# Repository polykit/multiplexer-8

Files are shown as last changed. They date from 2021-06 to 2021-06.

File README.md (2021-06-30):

# Polykit Multiplexer 16:8

This repository contains schematics and PCB layout of a 2x8 to 8 channel multiplexer. It can be used to switch between different waveforms of a polyphonic oscillator. It is based on four 4066 bilateral switches and can handle a 10Vpp signal. It is powered by +-12V Eurorack style power supply.

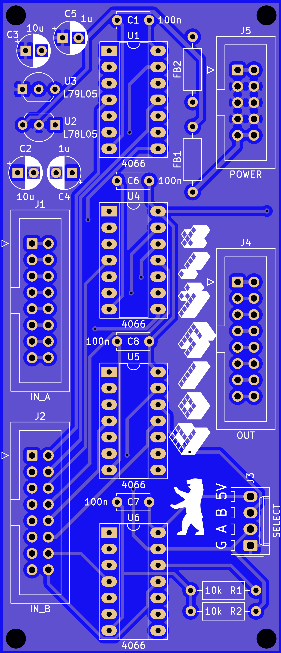
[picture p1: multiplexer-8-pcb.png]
Polykit Multiplexer 8 PCB


## References

https://www.ti.com/lit/ds/symlink/cd4066b.pdf

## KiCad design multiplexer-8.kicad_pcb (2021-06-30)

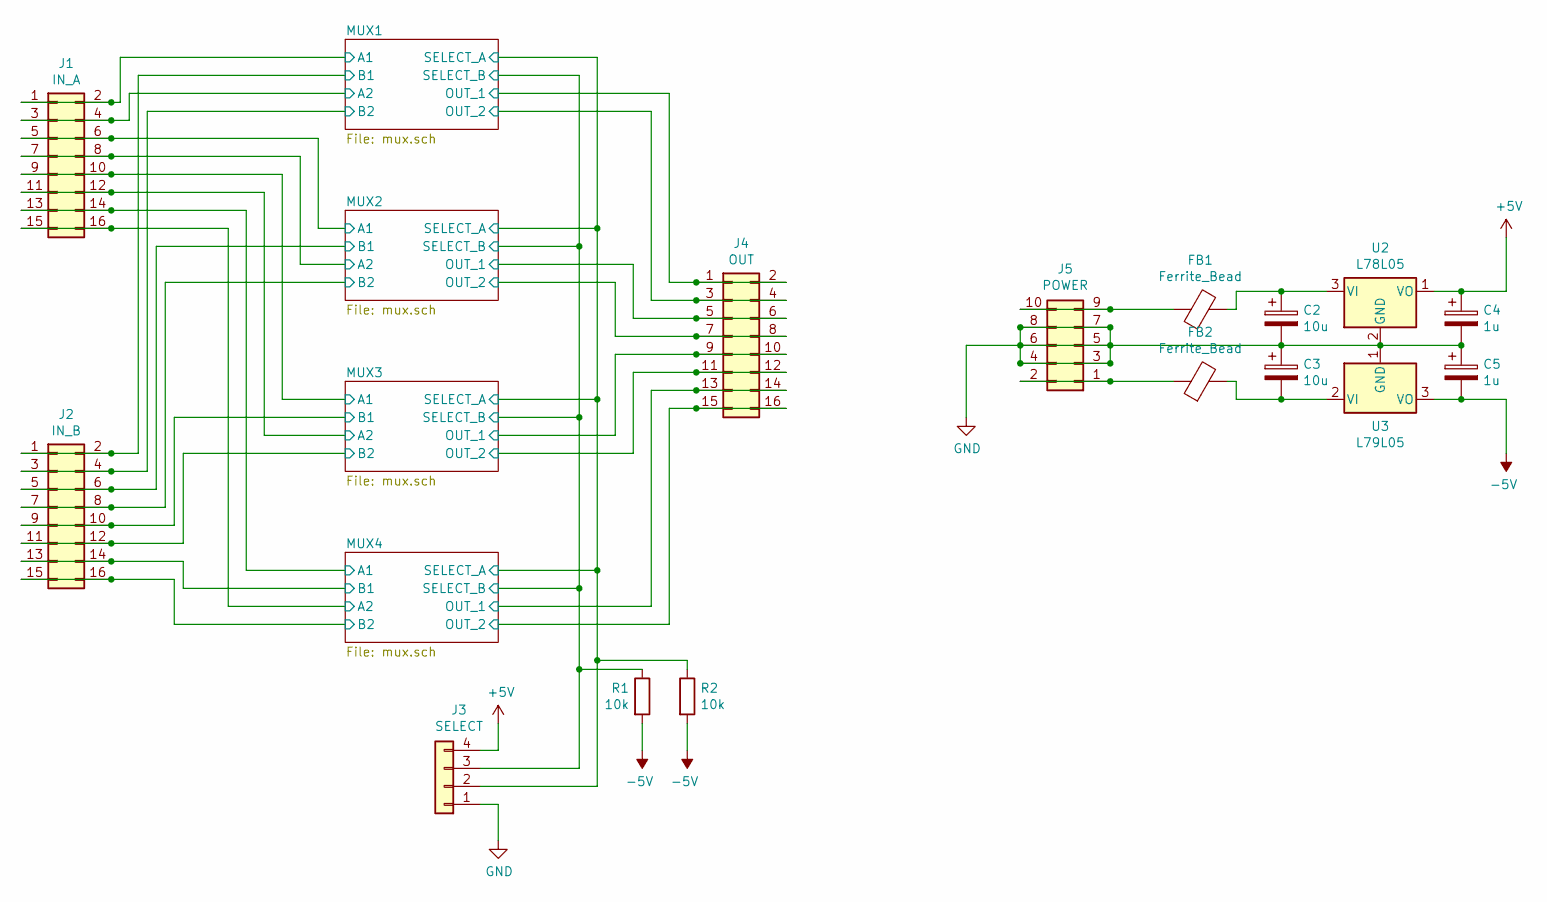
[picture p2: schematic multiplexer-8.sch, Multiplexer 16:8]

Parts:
C2, C3: 10u; CP_Radial_D5.0mm_P2.50mm
C4, C5: 1u; CP_Radial_D5.0mm_P2.50mm
FB1, FB2: Ferrite_Bead; R_Axial_DIN0207_L6.3mm_D2.5mm_P10.16mm_Horizontal
J1: IN_A; IDC-Header_2x08_P2.54mm_Vertical
J2: IN_B; IDC-Header_2x08_P2.54mm_Vertical
J3: SELECT; Molex_KK-254_AE-6410-04A_1x04_P2.54mm_Vertical
J4: OUT; IDC-Header_2x08_P2.54mm_Vertical
J5: POWER; IDC-Header_2x05_P2.54mm_Vertical
R1, R2: 10k; R_Axial_DIN0207_L6.3mm_D2.5mm_P10.16mm_Horizontal
U2: L78L05; TO-92_Inline_Wide
U3: L79L05; TO-92_Inline_Wide

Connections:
+5V: C4.1, J3.4, U2.1 (VO); also elsewhere on the board
-5V: C5.2, R1.2, R2.2, U3.3 (VO); also elsewhere on the board
/MUX1/A1: J1.1, J1.2; also elsewhere on the board
/MUX1/A2: J1.3, J1.4; also elsewhere on the board
/MUX1/B1: J2.1, J2.2; also elsewhere on the board
/MUX1/B2: J2.3, J2.4; also elsewhere on the board
/MUX1/OUT_1: J4.1, J4.2; also elsewhere on the board
/MUX1/OUT_2: J4.3, J4.4; also elsewhere on the board
/MUX1/SELECT_A: J3.2, R2.1; also elsewhere on the board
/MUX1/SELECT_B: J3.3, R1.1; also elsewhere on the board
/MUX2/A1: J1.5, J1.6; also elsewhere on the board
/MUX2/A2: J1.7, J1.8; also elsewhere on the board
/MUX2/B1: J2.5, J2.6; also elsewhere on the board
/MUX2/B2: J2.7, J2.8; also elsewhere on the board
/MUX2/OUT_1: J4.5, J4.6; also elsewhere on the board
/MUX2/OUT_2: J4.7, J4.8; also elsewhere on the board
/MUX3/A1: J1.9, J1.10; also elsewhere on the board
/MUX3/A2: J1.11, J1.12; also elsewhere on the board
/MUX3/B1: J2.9, J2.10; also elsewhere on the board
/MUX3/B2: J2.11, J2.12; also elsewhere on the board
/MUX3/OUT_1: J4.9, J4.10; also elsewhere on the board
/MUX3/OUT_2: J4.11, J4.12; also elsewhere on the board
/MUX4/A1: J1.13, J1.14; also elsewhere on the board
/MUX4/A2: J1.15, J1.16; also elsewhere on the board
/MUX4/B1: J2.13, J2.14; also elsewhere on the board
/MUX4/B2: J2.15, J2.16; also elsewhere on the board
/MUX4/OUT_1: J4.13, J4.14; also elsewhere on the board
/MUX4/OUT_2: J4.15, J4.16; also elsewhere on the board
GND: C2.2, C3.1, C4.2, C5.1, J3.1, J5.3, J5.4, J5.5, J5.6, J5.7, J5.8, U2.2 (GND), U3.1 (GND)
unnamed: C2.1, FB1.2, U2.3 (VI)
unnamed: C3.2, FB2.2, U3.2 (VI)
unnamed: FB1.1, J5.9, J5.10
unnamed: FB2.1, J5.1, J5.2

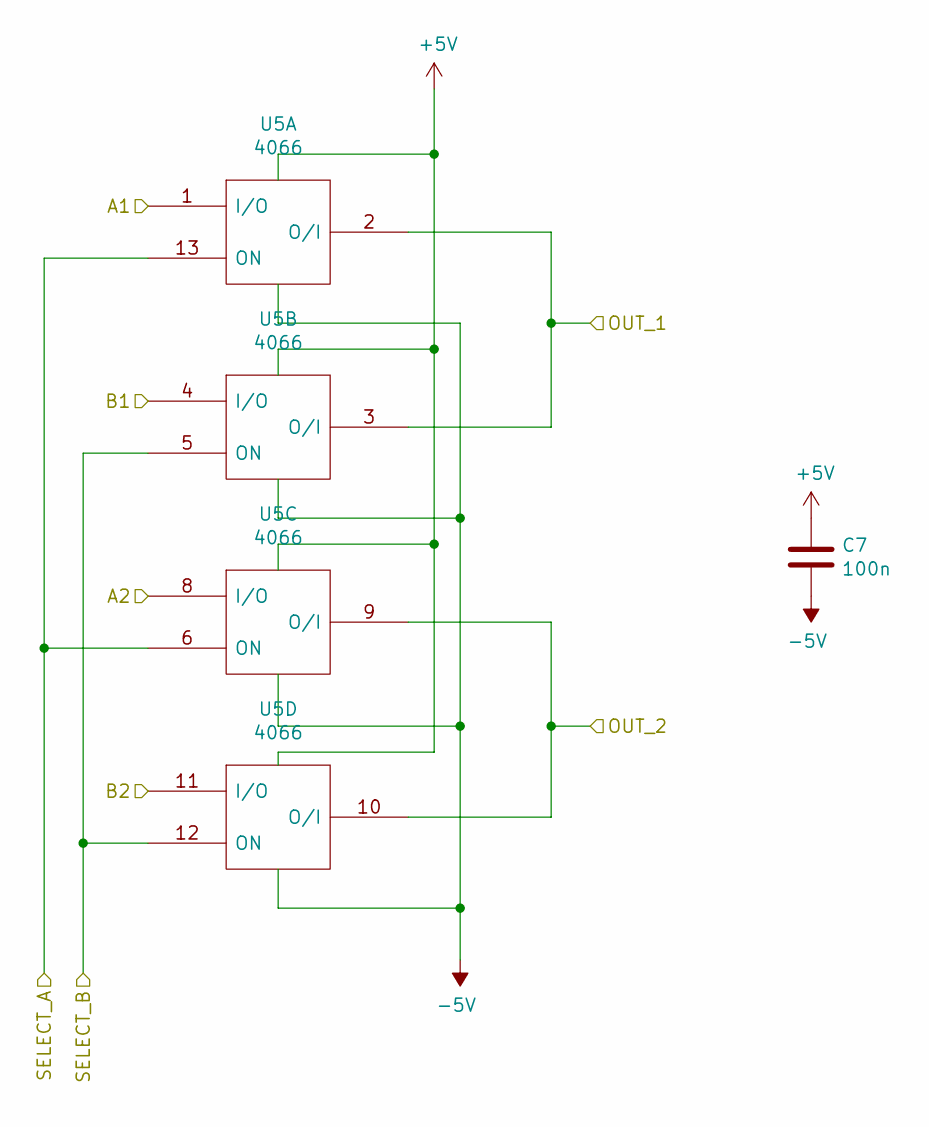
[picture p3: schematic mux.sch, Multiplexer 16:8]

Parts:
C1: 100n; C_Disc_D5.0mm_W2.5mm_P5.00mm
U1: 4066; DIP-14_W7.62mm_Socket_LongPads

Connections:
+5V: C1.1, U1.14 (Vdd); also elsewhere on the board
-5V: C1.2, U1.7 (Vss); also elsewhere on the board
/MUX1/A1: U1.1 (I/O); also elsewhere on the board
/MUX1/A2: U1.8 (I/O); also elsewhere on the board
/MUX1/B1: U1.4 (I/O); also elsewhere on the board
/MUX1/B2: U1.11 (I/O); also elsewhere on the board
/MUX1/OUT_1: U1.2 (O/I), U1.3 (O/I); also elsewhere on the board
/MUX1/OUT_2: U1.9 (O/I), U1.10 (O/I); also elsewhere on the board
/MUX1/SELECT_A: U1.6 (ON), U1.13 (ON); also elsewhere on the board
/MUX1/SELECT_B: U1.5 (ON), U1.12 (ON); also elsewhere on the board

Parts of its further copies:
C6, C7, C8: 100n; C_Disc_D5.0mm_W2.5mm_P5.00mm
U4, U5, U6: 4066; DIP-14_W7.62mm_Socket_LongPads

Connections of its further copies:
+5V: C6.1, C7.1, C8.1, U4.14 (Vdd), U5.14 (Vdd), U6.14 (Vdd); also elsewhere on the board
-5V: C6.2, C7.2, C8.2, U4.7 (Vss), U5.7 (Vss), U6.7 (Vss); also elsewhere on the board
/MUX1/SELECT_A: U4.6 (ON), U4.13 (ON), U5.6 (ON), U5.13 (ON), U6.6 (ON), U6.13 (ON); also elsewhere on the board
/MUX1/SELECT_B: U4.5 (ON), U4.12 (ON), U5.5 (ON), U5.12 (ON), U6.5 (ON), U6.12 (ON); also elsewhere on the board
/MUX2/A1: U4.1 (I/O); also elsewhere on the board
/MUX2/A2: U4.8 (I/O); also elsewhere on the board
/MUX2/B1: U4.4 (I/O); also elsewhere on the board
/MUX2/B2: U4.11 (I/O); also elsewhere on the board
/MUX2/OUT_1: U4.2 (O/I), U4.3 (O/I); also elsewhere on the board
/MUX2/OUT_2: U4.9 (O/I), U4.10 (O/I); also elsewhere on the board
/MUX3/A1: U5.1 (I/O); also elsewhere on the board
/MUX3/A2: U5.8 (I/O); also elsewhere on the board
/MUX3/B1: U5.4 (I/O); also elsewhere on the board
/MUX3/B2: U5.11 (I/O); also elsewhere on the board
/MUX3/OUT_1: U5.2 (O/I), U5.3 (O/I); also elsewhere on the board
/MUX3/OUT_2: U5.9 (O/I), U5.10 (O/I); also elsewhere on the board
/MUX4/A1: U6.1 (I/O); also elsewhere on the board
/MUX4/A2: U6.8 (I/O); also elsewhere on the board
/MUX4/B1: U6.4 (I/O); also elsewhere on the board
/MUX4/B2: U6.11 (I/O); also elsewhere on the board
/MUX4/OUT_1: U6.2 (O/I), U6.3 (O/I); also elsewhere on the board
/MUX4/OUT_2: U6.9 (O/I), U6.10 (O/I); also elsewhere on the board

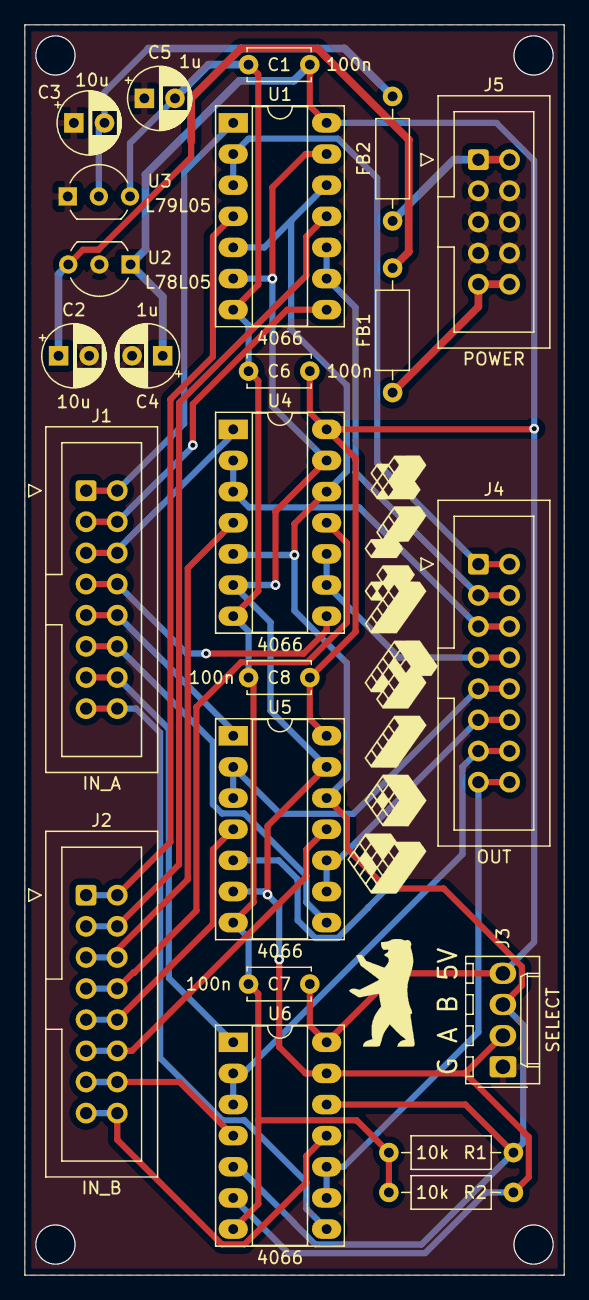
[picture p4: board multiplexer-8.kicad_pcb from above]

Board: 2 copper layers, 44.0 x 102.0 mm, 23 parts (0 on the bottom side), 33 nets.
